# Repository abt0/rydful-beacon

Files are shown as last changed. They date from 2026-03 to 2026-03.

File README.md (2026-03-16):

# Rydful Beacon

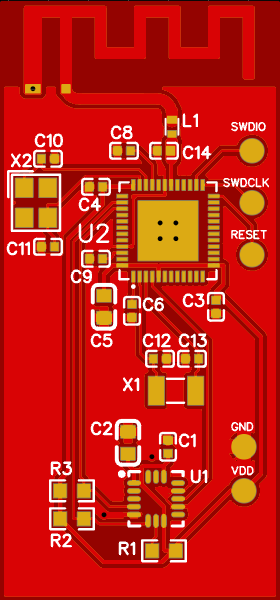
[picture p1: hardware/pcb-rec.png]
Rydful Beacon PCB


A motion-triggered BLE beacon application for Nordic nRF52 microcontrollers using the Zephyr RTOS. The device remains in sleep mode until motion is detected via an LIS3DH accelerometer, then starts BLE advertising to enable presence detection.

Designed for Rydful App: https://rydful.com

<br clear="left">

## Features

- **Hardware Interrupt-Driven Wake** – LIS3DH accelerometer's internal motion engine triggers MCU wake via GPIO interrupt (P0.02/INT1)
- **Ultra-Low Power Sleep** – MCU sleeps indefinitely with `k_sem_take(K_FOREVER)` until motion interrupt occurs (~3.9 µA total idle current)
- **Motion-Triggered Advertising** – BLE advertising starts only when motion exceeds hardware threshold (32mg default)
- **High-Pass Filtered Detection** – Gravity filtered out at 1Hz ODR in hardware, only acceleration changes trigger interrupt
- **Advertising Duty Cycling** – During active mode, advertising cycles 5s on / 7s off (~42% duty cycle) to reduce average power by ~45%
- **Configurable Timeouts** – Advertising stops after configurable period of no motion (default: 36 seconds, 3 full duty cycles)
- **Battery Voltage Monitoring** – ADC-based battery voltage measurement with percentage calculation, included in BLE advertising data (updated every 5 minutes)
- **Direct I2C Register Access** – Bypasses Zephyr sensor framework for reliable interrupt configuration
- **Android CDM Compatible** – 250-400ms connectable/scannable advertising interval for reliable companion app discovery

## Hardware Requirements

- **MCU**: Nordic nRF52832 (nRF52 DK)
- **Accelerometer**: LIS3DH or LIS2DH (I2C interface)
- **Battery**: 2.0-3.6V input (CR2032, 2× AAA/AA alkaline or lithium)

### Wiring (nRF52 DK with LIS3DH)

| LIS3DH Pin | nRF52 DK Pin | Description |
|---|---|---|
| SDA | P0.26 | I2C Data |
| SCL | P0.27 | I2C Clock |
| INT1 | P0.02 | Motion interrupt (required for low-power wake) |
| - | P0.03 (AIN1) | Battery voltage input |

## Supported Boards

| Board | Description | Use Case |
|---|---|---|
| `nrf52dk_nrf52832` | Nordic nRF52 DK | Development/testing with external LIS3DH |
| `rydful_custom` | Custom PCB | Production board with integrated LIS3DH |

## Configuration

### Hardware Motion Detection Parameters

These are defined in `src/main.c`:

| Parameter | Default | Description |
|---|---|---|
| `HW_MOTION_THRESHOLD_MG` | 32 mg | Acceleration threshold for motion detection |
| `HW_MOTION_DURATION` | 2 samples | Required samples above threshold (debounce) |
| `NO_MOTION_TIMEOUT_SEC` | 36 | Seconds of no motion before stopping advertising (3 full duty cycles) |
| `ADV_DUTY_ON_SEC` | 5 | Seconds of advertising per duty cycle |
| `ADV_DUTY_OFF_SEC` | 7 | Seconds of radio silence per duty cycle |

The LIS3DH operates at **1Hz ODR** in low-power mode (~2µA) and uses its internal high-pass filter to remove gravity, so only acceleration *changes* trigger the interrupt. Wake latency is ~1 second.

### Battery Monitoring

| Parameter | Default | Description |
|---|---|---|
| `BATTERY_LOW_THRESHOLD_MV` | 2000 mV | 0% battery threshold |
| `BATTERY_FULL_MV` | 3000 mV | 100% battery threshold |
| `BATTERY_UPDATE_INTERVAL_SEC` | 300 | Battery status update interval (5 minutes) |

### BLE Configuration

- **Device Name**: `Rydful_Beacon` (configurable via `CONFIG_BT_DEVICE_NAME`)
- **Service UUID**: `0xFEAA` (16-bit)
- **Manufacturer ID**: `0xFFFF` (development/testing)
- **Advertising Interval**: 250-400 ms (required for Android CDM compatibility)
- **Mode**: Connectable, scannable

### BLE Advertising Data

The manufacturer-specific data contains:
- Bytes 0-1: Manufacturer ID
- Byte 2: Battery percentage (0-100)
- Byte 3: Low battery flag (0x00 or 0x01)

## Building

### Prerequisites

- [nRF Connect SDK](https://docs.nordicsemi.com/bundle/ncs-latest/page/nrf/installation.html) installed
- West tool configured

### Build Commands

```bash
# Build for nRF52 DK (development/testing with external accelerometer)
west build -b nrf52dk/nrf52832 -p

# Build for Rydful Custom PCB (production board)
west build -b rydful_custom -p -- -DBOARD_ROOT=.
```

### Flash

```bash
# Flash nRF52 DK (direct connection)
west flash
```

## Flashing Custom PCB via nRF52 DK

The nRF52 DK can be used as a J-Link programmer to flash the custom PCB.

### Hardware Setup

1. **Disconnect** the nRF52 DK from USB
2. **Set the nRF power switch** to "VDD" (not "USB") on the DK
3. **Connect SWD wires** from DK P20 header to your custom PCB:

| DK P20 Pin | Custom PCB | Description |
|---|---|---|
| SWDIO | SWDIO | Debug data  |
| SWDCLK | SWDCLK | Debug clock |
| GND | GND | Ground |
| VTG | VDD | Target voltage sense (optional) |

4. **Power the custom PCB** via its own power source (external supply)
5. **Connect DK to USB** for programming

### Flash Command

```bash
# Build for custom PCB
west build -b rydful_custom -p -- -DBOARD_ROOT=.

# Flash via J-Link
west flash
```

### Troubleshooting

- **"No target detected"** – Check SWD wiring, ensure custom PCB is powered
- **"Could not connect"** – Verify SWDIO/SWDCLK connections, check for shorts
- **Use nRF Connect Programmer** – Alternative GUI tool for flashing `.hex` files from `build/zephyr/zephyr.hex`

### Using nrfjprog (Alternative)

```bash
# Erase and flash
nrfjprog --program build/zephyr/zephyr.hex --chiperase --verify
nrfjprog --reset
```

## How It Works

### State Machine

```
┌─────────────────────────────────────────────────────────────┐
│  SLEEP MODE                                                 │
│  • LIS3DH: Hardware threshold interrupt (>32mg) @ 1Hz       │
│  • nRF52: System ON sleep with LFXO (~1.8 µA)               │
│  • Total: ~3.9 µA                                           │
└──────────────────────┬──────────────────────────────────────┘
                       │ Motion exceeds threshold (~2s latency)
                       ▼
┌─────────────────────────────────────────────────────────────┐
│  ACTIVE MODE (duty-cycled: 5s ON / 7s OFF)                  │
│  • ON:  BLE advertising (connectable, 250-400ms, -12dBm TX) │
│  • OFF: Radio silent, MCU polling for motion (max 7s gap)   │
│  • Each motion interrupt resets 36-second timeout           │
│  • Duty cycle runs independently of motion events           │
│  • Average: ~30 µA                                          │
└──────────────────────┬──────────────────────────────────────┘
                       │ No motion for 36 seconds
                       ▼
              Back to SLEEP MODE
```

### Usage

1. **Power on** – Initialization sequence
2. **Sleep mode** – No BLE advertising, ultra-low power (~3.9 µA)
3. **Motion detected** – BLE advertising starts (~1 second wake latency)
4. **Active mode** – Advertising duty-cycles 5s on / 7s off; each motion event resets the 36-second timeout
5. **No motion** – After 36 seconds of no motion, advertising stops

### Monitoring

Connect via RTT console (production PCB) or serial (115200 baud) to view logs.

## Power Consumption

*Note: All estimates are for the production PCB (nRF52832 + LIS3DHTR + passives only).*

### Current Draw by State

| State | Current | Description |
|---|---|---|
| Sleep | ~3.9 µA | nRF52 System ON (~1.8µA with LFXO) + LIS3DH @ 1Hz (~2µA) |
| Active (duty-cycled) | ~30 µA avg | 5s advertising / 7s silent duty cycle (~42% radio on) |
| Active (ON phase) | ~55 µA | BLE connectable advertising @ 250-400ms, -12dBm TX |
| Active (OFF phase) | ~13 µA | Radio off, CPU polling for motion |
| Peak (TX burst) | ~7.5 mA | During BLE transmit events @ -12dBm (~380µs per event) |

### Component Breakdown (Sleep Mode)

| Component | Current | Notes |
|---|---|---|
| nRF52832 System ON (LFXO) | ~1.8 µA | RAM retained, RTC running, external 32.768kHz crystal |
| LIS3DHTR @ 1Hz LP mode | ~2 µA | Interrupt engine active, HP filter, 1s wake latency |
| GPIO leakage | ~0.1 µA | Minimal with proper configuration |
| **Total Sleep** | **~3.9 µA** | |

### Component Breakdown (Active Mode – ON Phase, 5s)

| Component | Current | Notes |
|---|---|---|
| BLE advertising | ~40 µA | 250-400ms interval, connectable/scannable, -12dBm TX |
| LIS3DHTR @ 1Hz | ~2 µA | Same ODR as sleep |
| ADC sampling (periodic) | ~1 µA avg | Brief spikes every 5 minutes |
| CPU overhead | ~10-12 µA | Processing interrupts, state management |
| **Total ON Phase** | **~55 µA** | 0.055 mA |

### Component Breakdown (Active Mode – OFF Phase, 7s)

| Component | Current | Notes |
|---|---|---|
| BLE advertising | 0 µA | Radio off |
| LIS3DHTR @ 1Hz | ~2 µA | Same ODR as sleep |
| ADC sampling (periodic) | ~1 µA avg | Brief spikes every 5 minutes |
| CPU overhead | ~10 µA | Polling loop (500ms wake intervals) |
| **Total OFF Phase** | **~13 µA** | 0.013 mA |

### Duty-Cycled Active Mode Average

```
I_active_avg = (I_on × T_on + I_off × T_off) / (T_on + T_off)
             = (55µA × 5s + 13µA × 7s) / (5s + 7s)
             = (275 + 91) / 12
             ≈ 30 µA (0.030 mA)
```

### Power Optimizations Applied

| Optimization | Impact | Trade-off |
|---|---|---|
| External 32.768kHz LFXO | ~70% MCU sleep reduction vs RC oscillator | None (hardware present) |
| Reduced TX power (-12dBm) | ~25% peak TX reduction, minimal avg impact | Tight 5m discovery range |
| LIS3DH 1Hz ODR | ~64% sensor sleep reduction | 1 second wake latency |
| **Advertising duty cycle (5s/7s)** | **~45% active mode reduction** (55→30 µA) | Up to 7s discovery gap |
| 36s no-motion timeout (3 duty cycles) | Minimizes active time | Aligned to duty cycle period |
| 5-minute battery updates | Negligible impact (<1 µA) | Less frequent battery status |

---

## Battery Life Calculations

*Production PCB with power optimizations: 1Hz accelerometer ODR, 5s/7s advertising duty cycle, 36s timeout, 5-min battery updates.*

### Supported Power Sources

| Battery Type | Nominal Voltage | Typical Capacity | Effective Capacity* |
|---|---|---|---|
| CR2032 | 3.0V | 225 mAh | ~150 mAh** |
| 2× AAA Alkaline | 3.0V (1.5V × 2) | 1,200 mAh | ~1,000 mAh |
| 2× AA Alkaline | 3.0V (1.5V × 2) | 2,850 mAh | ~2,400 mAh |
| 2× AA Lithium | 3.0V (1.5V × 2) | 3,500 mAh | ~3,000 mAh |

*Effective capacity accounts for ~15-20% derating due to voltage cutoff (2.0V minimum), temperature, and discharge curve.

**CR2032 Pulse Current Derating:** CR2032 batteries experience significant capacity reduction under pulse loads. While average current is low (~55 µA active), the 7.5 mA TX peaks (though brief, ~380µs every 325ms) cause additional derating. Effective capacity reduced from nominal 225 mAh to ~150 mAh for this application. For comparison: at 0.5 mA continuous draw CR2032 provides ~240 mAh, but at 3.0 mA only ~155 mAh remains available.

### Usage Pattern Definitions

| Pattern | Description | Daily Active Time | Trips/Day |
|---|---|---|---|
| **Parked Vehicle** | Garaged/parked, minimal vibration | ~5-15 min | 0-1 |
| **Weekend Rider** | Motorcycle/classic car, weekend use only | ~2-4 hours | 1-2 (weekends only) |
| **Commuter** | Daily work commute, 2× per day ~1h each | ~2 hours | 2 |
| **Daily Driver** | Multiple short trips throughout day | ~3 hours | 4-6 |
| **Heavy Use** | Delivery/rideshare, constant use | ~8-12 hours | 10-20 |

### Battery Life Formula

```
Total Daily Consumption (mAh/day) = (I_sleep × T_sleep) + (I_active × T_active)

Where:
  I_sleep  = 0.0039 mA (3.9 µA with external LFXO)
  I_active = 0.030 mA (duty-cycled average: 5s ON @ 55µA, 7s OFF @ 13µA)
  T_sleep  = 24 - T_active (hours)
  T_active = Active hours per day + (trips × timeout / 3600)
  timeout  = 36 seconds (advertising continues after last motion, 3 duty cycles)

Battery Life (days) = Effective_Capacity / Daily_Consumption
```

### Detailed Lifetime Estimates

#### CR2032 (150 mAh effective, pulse-derated)

| Usage Pattern | Active Hours/Day | Daily Draw (mAh) | Estimated Life |
|---|---|---|---|
| Parked Vehicle | 0.26h | 0.10 | **1,500 days** (~4.1 years)† |
| Weekend Rider | 0.59h (avg)* | 0.11 | **1,376 days** (~3.8 years)† |
| Commuter (2×/day) | 2.02h | 0.15 | **1,027 days** (~2.8 years) |
| Daily Driver | 3.05h | 0.17 | **867 days** (~2.4 years) |
| Heavy Use | 8.15h | 0.31 | **490 days** (~1.3 years) |

*Weekend rider averaged over 7 days
†CR2032 self-discharge ~10-15% per year; practical life 2-3 years for commuter/daily use due to pulse derating and environmental factors

#### 2× AAA Alkaline (1,000 mAh effective)

| Usage Pattern | Active Hours/Day | Daily Draw (mAh) | Estimated Life |
|---|---|---|---|
| Parked Vehicle | 0.26h | 0.10 | **10,000 days** (~27.4 years)† |
| Weekend Rider | 0.59h (avg) | 0.11 | **9,174 days** (~25.1 years)† |
| Commuter (2×/day) | 2.02h | 0.15 | **6,849 days** (~18.8 years)† |
| Daily Driver | 3.05h | 0.17 | **5,780 days** (~15.8 years)† |
| Heavy Use | 8.15h | 0.31 | **3,268 days** (~8.9 years)† |

†Limited by battery self-discharge (~2-3% per year), practical limit ~5-7 years.

#### 2× AA Alkaline (2,400 mAh effective)

| Usage Pattern | Active Hours/Day | Daily Draw (mAh) | Estimated Life |
|---|---|---|---|
| Parked Vehicle | 0.26h | 0.10 | **24,000 days** (~66 years)† |
| Weekend Rider | 0.59h (avg) | 0.11 | **22,018 days** (~60 years)† |
| Commuter (2×/day) | 2.02h | 0.15 | **16,438 days** (~45 years)† |
| Daily Driver | 3.05h | 0.17 | **13,873 days** (~38 years)† |
| Heavy Use | 8.15h | 0.31 | **7,843 days** (~21 years)† |

†Alkaline batteries self-discharge ~2-3% per year. Actual life limited to ~5-7 years maximum regardless of load.

#### 2× AA Lithium (3,000 mAh effective)

| Usage Pattern | Active Hours/Day | Daily Draw (mAh) | Estimated Life |
|---|---|---|---|
| Parked Vehicle | 0.26h | 0.10 | **30,000 days** (~82 years)† |
| Weekend Rider | 0.59h (avg) | 0.11 | **27,523 days** (~75 years)† |
| Commuter (2×/day) | 2.02h | 0.15 | **20,548 days** (~56 years)† |
| Daily Driver | 3.05h | 0.17 | **17,341 days** (~47 years)† |
| Heavy Use | 8.15h | 0.31 | **9,804 days** (~27 years)† |

†Lithium batteries have ~1% annual self-discharge. Practical limit ~10 years.

### Commuter Scenario Deep Dive (2× daily, ~1h each)

This is a common use case: daily work commute with two trips.

**Calculation breakdown:**
- Morning commute: 1 hour active
- Evening commute: 1 hour active
- Post-trip timeout: 36 seconds × 2 trips = 1.2 minutes
- **Total active time**: 2h 1.2min/day ≈ 2.02 hours

**Daily energy consumption:**
```
Sleep:   (24 - 2.02)h × 0.0039mA = 0.086 mAh
Active:  2.02h × 0.030mA         = 0.061 mAh
─────────────────────────────────────────────
Total:                           = 0.146 mAh/day
```

| Battery Type | Capacity | Estimated Life | Practical Reality |
|---|---|---|---|
| CR2032 | 150 mAh | **1,027 days** (~2.8 years) | 2-3 years typical |
| 2× AAA | 1,000 mAh | **6,849 days** (~18.8 years)† | 5-7 years (self-discharge limit) |
| 2× AA | 2,400 mAh | **16,438 days** (~45 years)† | 5-7 years (self-discharge limit) |
| 2× AA Lithium | 3,000 mAh | **20,548 days** (~56 years)† | 10+ years (self-discharge limit) |

†Limited by battery self-discharge, not device consumption

### Temperature Impact

Battery performance degrades significantly in extreme temperatures:

| Temperature | Capacity Factor | Notes |
|---|---|---|
| -20°C to -10°C | 50-70% | Severe cold reduces capacity |
| -10°C to 0°C | 70-85% | Cold weather impact |
| 0°C to 25°C | 85-100% | Optimal operating range |
| 25°C to 45°C | 90-100% | Warm, generally fine |
| >45°C | Reduced lifespan | Accelerated self-discharge |

**Recommendation**: For vehicles parked outdoors in extreme climates, use **lithium primary cells** (2× AA Lithium) which maintain 90%+ capacity down to -40°C.

### Battery Selection Guide

| Use Case | Recommended | Rationale |
|---|---|---|
| **Motorcycle (Weekend)** | 2× AAA | AAA: 5-7 years (self-discharge limited), better than CR2032 for longevity |
| **Daily Commuter** | 2× AAA | **5-7 years** (self-discharge limited), compact form factor |
| **Daily Commuter (extended)** | 2× AA | **5-7 years** (self-discharge limited), best longevity |
| **Delivery Vehicle** | 2× AA or 2× AA Lithium | AA: ~5 years, Lithium: 10+ years |
| **Garage Queen** | 2× AAA | Multi-year life, minimal replacement (AAA better than CR2032) |
| **Extreme Cold Climate** | 2× AA Lithium | Maintains capacity at low temps, 10+ years |
| **Compact Installation** | CR2032 | Small size, **2-3 years typical** (pulse current limits lifespan) |

### Quick Reference: Months Until Replacement

|  | CR2032** | 2× AAA | 2× AA | 2× AA Li |
|--|---|---|---|---|
| **Parked** | 49 mo | 60+ mo* | 60+ mo* | 120+ mo* |
| **Weekend** | 45 mo | 60+ mo* | 60+ mo* | 120+ mo* |
| **Commuter** | **34 mo** | 60+ mo* | 60+ mo* | 120+ mo* |
| **Daily** | 28 mo | 60+ mo* | 60+ mo* | 120+ mo* |
| **Heavy** | 16 mo | 60+ mo* | 60+ mo* | 120+ mo* |

*Limited by battery self-discharge (~5-7 years for alkaline, ~10 years for lithium), not device consumption
**CR2032 estimates account for pulse current derating; real-world life often 2-3 years for commuter/daily use due to environmental factors

---

## Case Designs

The project includes 3D-printable case designs for different battery configurations:

### Available Cases

| Case Type | Battery | Design File | STL Files | Dimensions | Features |
|---|---|---|---|---|---|
| **Circular** | CR2032 | `circular.scad` | `circular_base.stl`, `circular_lid.stl` | Ø35mm × 12.5mm | Compact circular design, snap-fit lid, mounting tabs |
| **Rectangular** | 2×AA | `rectangular.scad` | `rectangular_base.stl`, `rectangular_lid.stl` | 89mm × 40mm × 15mm | Side-by-side AA batteries, spring contacts, PCB rails |

### Case Features

**Circular Case**
- Designed for CR2032 coin cell battery
- 30mm diameter circular PCB mounting
- 3 tapered support nubs at 90°/210°/330° angles
- Snap-fit lid with 0.05mm interference fit for MJF printing
- Mounting tabs with 3.2mm screw holes
- "Rydful" engraved text on lid
- Fingernail pry notches for easy lid removal

**Rectangular Case**
- Designed for 2×AA batteries in side-by-side configuration
- Spring contact pockets for reliable battery connections
- PCB slide-in rails with L-shaped channels
- 4 corner standoffs for PCB support
- Divider wall between battery and PCB sections
- Snap-fit lid with multiple engagement points
- Battery cradle with cylindrical channels
- "Rydful" engraved text on lid

### 3D Printing

- **Recommended material**: MJF (Multi Jet Fusion) or FDM with PETG/ABS
- **Layer height**: 0.2mm for FDM
- **Infill**: 20-30% (cases are primarily hollow)
- **Orientation**: Print with flat side down for best surface finish
- **Post-processing**: Remove support material, check snap-fit engagement

### Assembly

1. Install batteries in designated compartments
2. Route PCB into case (slide-in rails for rectangular case)
3. Ensure proper alignment of snap-fit features
4. Press lid firmly until snap engagement is felt
5. Test lid removal using pry notches if needed

SPDX-License-Identifier: Apache-2.0

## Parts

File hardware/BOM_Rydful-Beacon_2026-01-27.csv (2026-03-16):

ID | Name | Designator | Footprint | Quantity | Supplier | Supplier Part | Price
1 | 100nF | C1,C3,C4,C6 | C0402 | 4 | LCSC | C60474 | 0.001
2 | 10uF | C2 | C0603 | 1 | LCSC | C19702 | 0.007
3 | 4.7uF | C5 | C0603 | 1 | LCSC | C18185770 | 0.011
4 | 100pF | C8 | C0402 | 1 | LCSC | C526991 | 0.001
5 | 1uF | C9 | C0402 | 1 | LCSC | C29266 | 0.003
6 | 6pF | C10,C11 | C0402 | 2 | LCSC | C696878 | 0.001
7 | 15pF | C12,C13 | C0402 | 2 | LCSC | C1548 | 0.001
8 | 0.8pF | C14 | C0402 | 1 | LCSC | C40459 | 0.002
9 | 3.9nH | L1 | IND-SMD_L1.0-W0.5-2 | 1 | LCSC | C98062 | 0.032
10 | 10kΩ | R1 | R0402 | 1 | LCSC | C25744 | 0.001
11 | 4.7kΩ | R2,R3 | R0402 | 2 | LCSC | C25900 | 0.001
12 | LIS3DH | U1 | LGA-16_L3.0-W3.0-P0.50-TL | 1 | LCSC | C15134 | 0.765
13 | NRF52832 V2 | U2 | QFN-48_L6.0-W6.0-P0.40-BL-EP3.8 | 1 | LCSC | C77540 | 2.807
14 | 32.768kHz | X1 | CRYSTAL-SMD_L3.2-W1.5-FC-135R32.7680KF-A3 | 1 | LCSC | C37635362 | 0.18
15 | 32MHz | X2 | CRYSTAL-SMD_4P-L2.5-W2.0-BL | 1 | LCSC | C524677 | 0.17

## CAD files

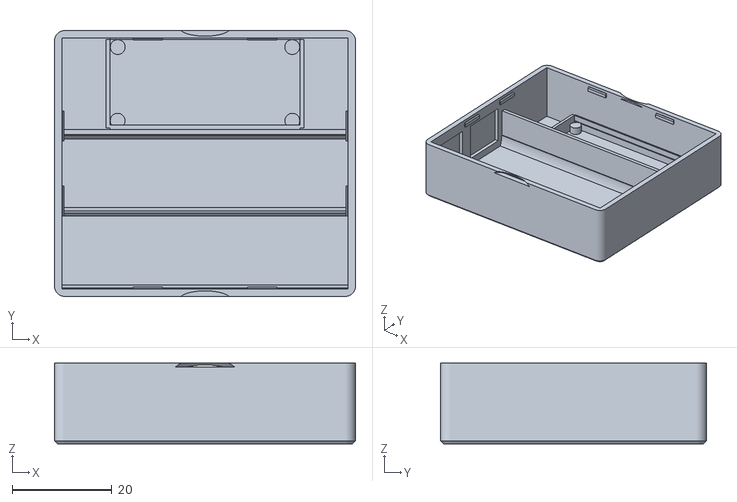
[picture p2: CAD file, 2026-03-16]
case/rectangular_base.stl
60.5 x 53.4 x 16.2

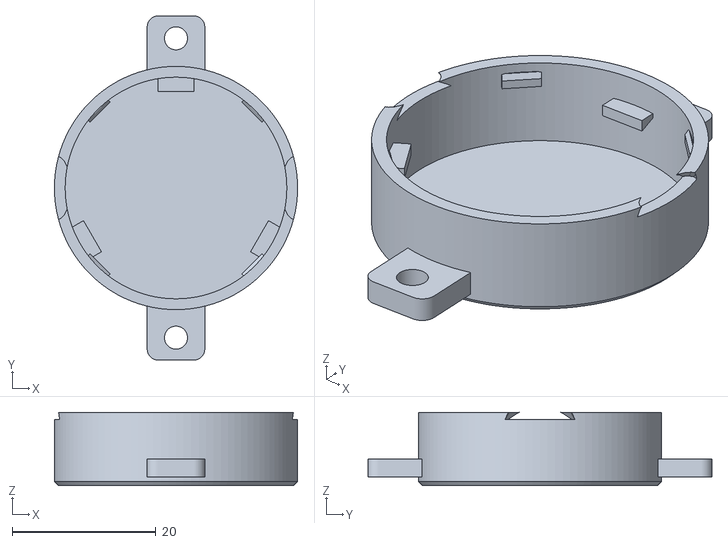
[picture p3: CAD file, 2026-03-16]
case/circlular_base.stl
33.8 x 47.8 x 10.2

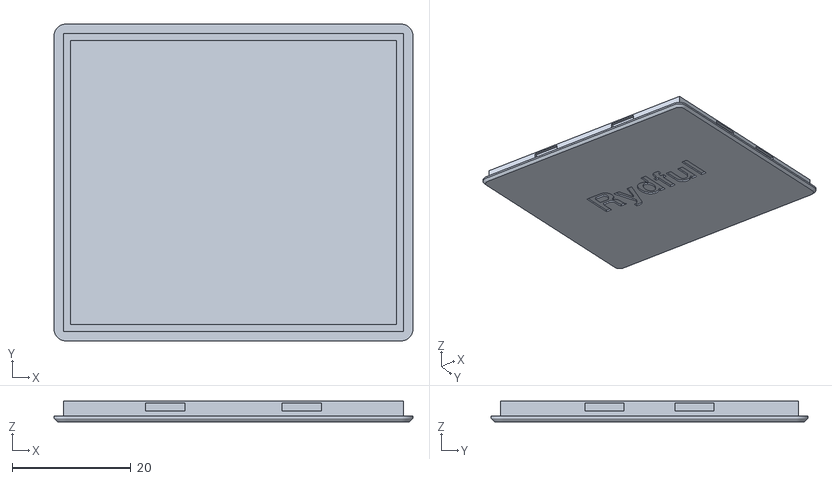
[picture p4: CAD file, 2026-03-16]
case/rectangular_lid.stl
60.5 x 53.4 x 3.50

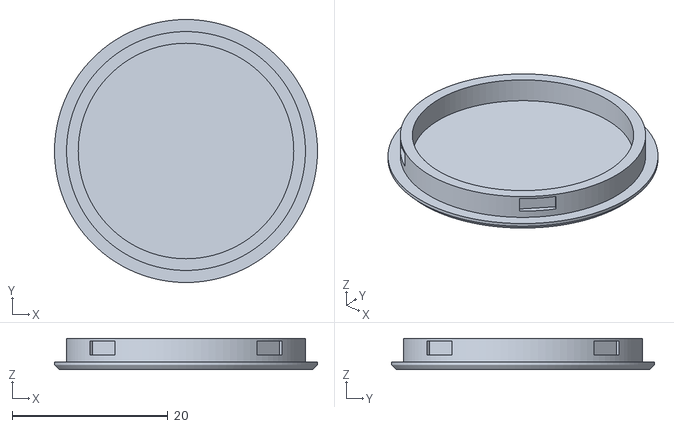
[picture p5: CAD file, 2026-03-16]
case/circular_lid.stl
33.8 x 33.8 x 4.00

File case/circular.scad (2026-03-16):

// ==============================================
// Rydful-Beacon Case v6 — JLC3DP MJF
// - No ring ledge (holder too close to PCB edge)
// - 3 tapered nubs at 90°/210°/330° for PCB support
// - 0.5mm snap bumps + 0.05mm interference skirt fit
// - Fingernail pry notches at ±X (away from tabs)
// - Orient PCB: holder long axis along ±X
// ==============================================

pcb_dia       = 30;
pcb_thk       = 1.0;
comp_h        = 2.0;     // Max component height above PCB
batt_h        = 6.0;     // BS-8-1 + CR2032 below PCB (0.8mm margin)

wall          = 1.5;
gap           = 0.4;     // Radial PCB clearance
floor_h       = 1.2;
ceil_h        = 1.0;
chamfer       = 0.6;

// Snap-fit — firmer engagement
snap_bump     = 0.5;     // Bump protrusion
snap_h        = 1.5;     // Bump height
snap_chamf    = 0.6;     // Entry chamfer

skirt_d       = 3.0;     // Lid skirt depth (was 2.5)
lid_gap       = 0.05;    // Near-zero for interference fit (MJF ±0.2mm)

tab_w         = 8.0;
tab_ext       = 7.0;
tab_h         = 2.5;
screw_d       = 3.2;
tab_r         = 1.5;

engrave_depth = 0.4;   // Text engraving depth (mm)
engrave_w     = 16;    // Text width (mm)

$fn = 100;

// Derived
ir = pcb_dia/2 + gap;
or = ir + wall;
cav_h = batt_h + pcb_thk + comp_h;
base_h = floor_h + cav_h;
pcb_z = floor_h + batt_h;

echo(str("Outer Ø=", or*2, "  Base H=", base_h, "  Total=", base_h + ceil_h));
echo(str("PCB Z=", pcb_z, "  Inner Ø=", ir*2));

// ==============================================
// CHAMFERED CYLINDER
// ==============================================
module cham_cyl_bot(r, h, c) {
    hull() {
        translate([0, 0, c])
            cylinder(h = h - c, r = r);
        cylinder(h = 0.01, r = r - c);
    }
}

module cham_cyl_top(r, h, c) {
    hull() {
        cylinder(h = h - c, r = r);
        translate([0, 0, h - 0.01])
            cylinder(h = 0.01, r = r - c);
    }
}

// ==============================================
// MOUNT TAB
// ==============================================
module mount_tab() {
    overlap = 3;
    total_l = tab_ext + overlap;
    difference() {
        hull() {
            translate([-tab_w/2, -overlap, 0])
                cube([tab_w, 0.01, tab_h]);
            translate([-tab_w/2 + tab_r, total_l - overlap - tab_r, 0])
                cylinder(h = tab_h, r = tab_r);
            translate([tab_w/2 - tab_r, total_l - overlap - tab_r, 0])
                cylinder(h = tab_h, r = tab_r);
        }
        translate([0, tab_ext - tab_r - screw_d/2, -0.1])
            cylinder(h = tab_h + 0.2, d = screw_d);
    }
}

// ==============================================
// PCB SUPPORT NUBS
// ==============================================
// Tapered nubs on interior wall at pcb_z height
// Positioned in equilateral triangle at 90°/210°/330°
// All 30°+ away from ±X where holder pads reach PCB edge
module pcb_support_nubs() {
    nub_w = 5;       // Width along wall (mm)
    nub_depth = 2.0; // How far nub sticks inward (inner edge at 13.4mm from center)
    nub_h = 1.2;     // Height (supports PCB from below)

    // Nub positions: 90° (+Y, top), 210°, 330° — equilateral triangle
    // ALL positions are 30°+ away from ±X (holder long axis)
    // Holder short axis only reaches 7.85mm from center, so
    // at these angles the holder edge is well inside the nub zone.
    for (a = [90, 210, 330]) {
        rotate([0, 0, a])
        translate([ir - nub_depth, -nub_w/2, pcb_z - nub_h])
        hull() {
            // Full shelf at wall
            cube([0.1, nub_w, nub_h]);
            // Tapered inner edge for easy PCB drop-in
            translate([nub_depth, 0, nub_h - 0.4])
                cube([0.1, nub_w, 0.4]);
        }
    }
}

// ==============================================
// BASE
// ==============================================
module base() {
    difference() {
        union() {
            // Main shell
            cham_cyl_bot(or, base_h, chamfer);

            // Tabs
            translate([0, or, floor_h])
                mount_tab();
            rotate([0, 0, 180])
            translate([0, or, floor_h])
                mount_tab();

            // Snap bumps — 4x on inner wall near top
            // (added after hollow cut below)
        }

        // Hollow interior
        translate([0, 0, floor_h])
            cylinder(h = cav_h + 1, r = ir);

        // Fingernail pry notches — scoop at lid/base seam
        // At 0° and 180° (±X) — away from tabs (±Y) and nubs
        for (a = [0, 180]) {
            rotate([0, 0, a])
            translate([or - 1.2, 0, base_h - 1.0])
            scale([1, 2.5, 1])
            hull() {
                translate([0, 0, 0]) cylinder(d = 4, h = 0.01, $fn = 24);
                translate([1.5, 0, 2.0]) cylinder(d = 3, h = 0.01, $fn = 24);
            }
        }
    }

    // PCB support nubs (added after hollow)
    pcb_support_nubs();

    // Snap bumps — protrude inward from wall into cavity
    // Lid skirt slides past these; grooves in skirt catch them
    for (i = [0:3]) {
        a = i * 90 + 45;
        rotate([0, 0, a])
        translate([ir - snap_bump, -2, base_h - skirt_d + 0.5])
        hull() {
            // Full bump at wall
            translate([snap_bump - 0.1, 0, 0])
                cube([0.1, 4, snap_h - snap_chamf]);
            // Tapered tip toward center (entry chamfer)
            cube([0.1, 4, snap_h - snap_chamf]);
            // Chamfer top for smooth lid insertion
            translate([snap_bump - 0.1, 0, snap_h - snap_chamf])
                cube([0.1, 4, snap_chamf]);
        }
    }
}

// ==============================================
// LID
// ==============================================
module lid() {
    skirt_or = ir - lid_gap;         // Skirt outer = fits inside base wall
    skirt_ir = skirt_or - wall;      // Skirt inner

    difference() {
        union() {
            // Ceiling
            cham_cyl_top(or, ceil_h, chamfer);

            // Skirt (internal, nests inside base)
            translate([0, 0, -skirt_d])
            difference() {
                cylinder(h = skirt_d, r = skirt_or);
                translate([0, 0, -0.01])
                    cylinder(h = skirt_d + 0.02, r = skirt_ir);
            }
        }

        // Snap grooves — channels in skirt outer surface
        // When lid is inserted, bumps deflect the skirt inward,
        // then pop into these grooves for a click-lock
        for (i = [0:3]) {
            a = i * 90 + 45;
            rotate([0, 0, a])
            translate([skirt_or - snap_bump - 0.2, -2.3, -skirt_d + 0.3])
                cube([snap_bump + 0.4, 4.6, snap_h + 0.3]);
        }

        // Engraved "Rydful" text centered on lid top
        translate([0, 0, ceil_h - engrave_depth])
            linear_extrude(engrave_depth + 0.01)
                resize([engrave_w, 0], auto=true)
                    text("Rydful", halign="center", valign="center",
                         font="Liberation Sans:style=Bold");
    }
}

// ==============================================
// RENDER — comment out for export
// ==============================================
// base();
// rotate([180,0,0]) lid();

color("DimGray") base();
color("SlateBlue", 0.7) translate([0, 0, base_h]) lid();
%translate([0, 0, pcb_z]) cylinder(h = pcb_thk, r = pcb_dia/2);
%translate([0, 0, floor_h + 0.5]) cylinder(h = 3.2, d = 20);

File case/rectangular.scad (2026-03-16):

// =============================================
// Rydful-Beacon Rectangular Case v1 — 2×AA
// - 2×AA side by side with spring contacts
// - PCB 17.8×38.1mm beside batteries
// - Snap-fit lid, rounded corners
// - Orient: batteries along X, PCB beside in Y
// =============================================

// AA Battery
aa_dia        = 14.5;   // Battery diameter
aa_len        = 50.5;   // Battery length (incl. positive nub)
spring_cl     = 3.5;    // Spring contact clearance per end
batt_gap      = 1.0;    // Gap between two batteries
batt_cl       = 0.5;    // Battery clearance to walls
cradle_depth  = 3.0;    // Cradle channel depth

// PCB
pcb_l         = 38.1;   // Length (X)
pcb_w         = 17.8;   // Width (Y)
pcb_thk       = 1.6;
comp_h        = 2.0;    // Max component height (top side)
pcb_gap       = 0.3;    // Clearance around PCB

// Case
wall          = 1.5;
floor_h       = 1.2;
ceil_h        = 1.0;
corner_r      = 2.0;
chamfer       = 0.6;
div_wall      = 1.0;    // Divider between battery/PCB sections

// Snap-fit
snap_bump     = 0.4;
snap_h        = 1.2;
snap_chamf    = 0.3;

// Lid
skirt_d       = 2.5;
lid_gap       = 0.1;
sk_wall       = 1.2;    // Skirt wall thickness

// PCB support
standoff_h    = 2.0;
standoff_d    = 3.0;

// Text engraving
engrave_depth = 0.4;
engrave_w     = 30;     // Text width (mm)

// Spring contact pockets
contact_w     = 12.0;   // Contact plate width
contact_h     = 10.0;   // Contact plate height
contact_d     = 1.0;    // Pocket depth into wall

$fn = 60;

// ---- Derived ----
batt_sec_x = aa_len + 2 * spring_cl;
batt_sec_y = 2 * aa_dia + batt_gap + 2 * batt_cl;
pcb_sec_y  = pcb_w + 2 * pcb_gap;

cav_x = batt_sec_x;
cav_y = batt_sec_y + div_wall + pcb_sec_y;
cav_z = aa_dia + batt_cl;

ext_x = cav_x + 2 * wall;
ext_y = cav_y + 2 * wall;
base_h = floor_h + cav_z;

// PCB origin inside cavity
pcb_ox = wall + (cav_x - pcb_l) / 2;
pcb_oy = wall + batt_sec_y + div_wall + pcb_gap;

echo(str("Case: ", ext_x, " × ", ext_y, " × ", base_h + ceil_h, " mm"));
echo(str("Battery section: ", batt_sec_x, " × ", batt_sec_y, " mm"));
echo(str("PCB section: ", cav_x, " × ", pcb_sec_y, " mm"));

// =============================================
// ROUNDED RECTANGLE (2D)
// =============================================
module rrect(x, y, r) {
    offset(r) offset(-r)
        square([x, y]);
}

// =============================================
// CHAMFERED ROUNDED RECTANGLE
// =============================================
module cham_rrect_bot(x, y, h, r, c) {
    hull() {
        linear_extrude(0.01)
            translate([c, c])
                rrect(x - 2*c, y - 2*c, max(r - c, 0.1));
        translate([0, 0, c])
            linear_extrude(h - c)
                rrect(x, y, r);
    }
}

module cham_rrect_top(x, y, h, r, c) {
    hull() {
        linear_extrude(h - c)
            rrect(x, y, r);
        translate([c, c, h - 0.01])
            linear_extrude(0.01)
                rrect(x - 2*c, y - 2*c, max(r - c, 0.1));
    }
}

// =============================================
// BASE
// =============================================
module base() {
    difference() {
        // Outer shell (chamfered bottom edge)
        cham_rrect_bot(ext_x, ext_y, base_h, corner_r, chamfer);

        // Internal cavity
        translate([wall, wall, floor_h])
            cube([cav_x, cav_y, cav_z + 1]);

        // Spring contact pockets — recesses in end walls (glue contacts in)
        for (i = [0, 1]) {
            batt_cy = wall + batt_cl + aa_dia/2 + i * (aa_dia + batt_gap);
            pocket_z = floor_h + cradle_depth - 1;

            // Negative end (X=0 wall)
            translate([wall - contact_d, batt_cy - contact_w/2, pocket_z])
                cube([contact_d + 0.1, contact_w, contact_h]);
            // Positive end (X=max wall)
            translate([wall + cav_x - 0.1, batt_cy - contact_w/2, pocket_z])
                cube([contact_d + 0.1, contact_w, contact_h]);
        }

        // Fingernail pry notches — centered on long sides
        for (dy = [0, ext_y]) {
            translate([ext_x/2, dy, base_h - 0.8])
            scale([3, 1, 1])
            hull() {
                cylinder(d = 4, h = 0.01, $fn = 24);
                translate([0, dy == 0 ? -1.2 : 1.2, 1.5])
                    cylinder(d = 3, h = 0.01, $fn = 24);
            }
        }
    }

    // ---- Internal features (added after hollow) ----

    // Battery cradle — raised floor with cylindrical channels
    difference() {
        translate([wall, wall, floor_h])
            cube([batt_sec_x, batt_sec_y, cradle_depth]);

        for (i = [0, 1]) {
            by = wall + batt_cl + aa_dia/2 + i * (aa_dia + batt_gap);
            translate([wall - 0.1, by, floor_h + cradle_depth])
                rotate([0, 90, 0])
                    cylinder(d = aa_dia + 0.6, h = batt_sec_x + 0.2);
        }
    }

    // Divider wall (70% height — open top for wire routing)
    translate([wall, wall + batt_sec_y, floor_h])
        cube([cav_x, div_wall, cav_z * 0.7]);

    // PCB standoffs — 4 posts near PCB corners
    for (dx = [1.5, pcb_l - 1.5], dy = [1.5, pcb_w - 1.5])
        translate([pcb_ox + dx, pcb_oy + dy, floor_h])
            cylinder(d = standoff_d, h = standoff_h, $fn = 20);

    // PCB slide-in rails (Y sides) — L-shaped channels that capture PCB edges
    rail_lip   = 0.6;    // Lip overhang over PCB edge
    rail_wall  = 0.8;    // Rail outer wall thickness
    rail_h     = standoff_h + pcb_thk + 0.3;  // Full height incl. lip
    rail_slot  = pcb_thk + 0.2;  // Slot height (PCB + clearance)

    for (side = [0, 1]) {
        ry = side == 0
            ? pcb_oy - rail_wall          // Near side
            : pcb_oy + pcb_w;             // Far side
        translate([pcb_ox, ry, floor_h]) {
            // Base wall (full height below PCB lip)
            cube([pcb_l, rail_wall, standoff_h]);
            // Upper wall (below PCB)
            cube([pcb_l, rail_wall + rail_lip, standoff_h]);
            // Lip overhang (above PCB slot)
            translate([0, 0, standoff_h + rail_slot])
                cube([pcb_l, rail_wall + rail_lip, rail_h - standoff_h - rail_slot]);
        }
    }

    // PCB end stops (X sides) — short walls at both ends
    stop_h = standoff_h + pcb_thk + 0.3;
    stop_w = 0.8;
    // Near X end
    translate([pcb_ox - stop_w, pcb_oy, floor_h])
        cube([stop_w, pcb_w, stop_h]);
    // Far X end
    translate([pcb_ox + pcb_l, pcb_oy, floor_h])
        cube([stop_w, pcb_w, stop_h]);

    // Snap bumps — protrude from inner walls into cavity
    bump_z = base_h - skirt_d + 0.5;
    bump_w = 6;

    // On Y walls (long sides)
    for (sx = [wall + cav_x * 0.3, wall + cav_x * 0.7]) {
        // Near Y wall
        translate([sx - bump_w/2, wall, bump_z])
        hull() {
            cube([bump_w, snap_bump, snap_h - snap_chamf]);
            translate([0, 0, snap_h - snap_chamf])
                cube([bump_w, 0.1, snap_chamf]);
        }
        // Far Y wall
        translate([sx - bump_w/2, wall + cav_y - snap_bump, bump_z])
        hull() {
            cube([bump_w, snap_bump, snap_h - snap_chamf]);
            translate([0, snap_bump - 0.1, snap_h - snap_chamf])
                cube([bump_w, 0.1, snap_chamf]);
        }
    }

    // On X walls (short sides)
    for (sy = [wall + cav_y * 0.35, wall + cav_y * 0.65]) {
        // Near X wall
        translate([wall, sy - bump_w/2, bump_z])
        hull() {
            cube([snap_bump, bump_w, snap_h - snap_chamf]);
            translate([0, 0, snap_h - snap_chamf])
                cube([0.1, bump_w, snap_chamf]);
        }
        // Far X wall
        translate([wall + cav_x - snap_bump, sy - bump_w/2, bump_z])
        hull() {
            cube([snap_bump, bump_w, snap_h - snap_chamf]);
            translate([snap_bump - 0.1, 0, snap_h - snap_chamf])
                cube([0.1, bump_w, snap_chamf]);
        }
    }
}

// =============================================
// LID
// =============================================
module lid() {
    skirt_x = cav_x - 2 * lid_gap;
    skirt_y = cav_y - 2 * lid_gap;
    bump_w  = 6;

    difference() {
        union() {
            // Top plate (chamfered top edge)
            cham_rrect_top(ext_x, ext_y, ceil_h, corner_r, chamfer);

            // Skirt (nests inside base cavity)
            translate([wall + lid_gap, wall + lid_gap, -skirt_d])
            difference() {
                cube([skirt_x, skirt_y, skirt_d]);
                translate([sk_wall, sk_wall, -0.01])
                    cube([skirt_x - 2*sk_wall, skirt_y - 2*sk_wall,
                          skirt_d + 0.02]);
            }
        }
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

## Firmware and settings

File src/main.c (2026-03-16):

/*
 * BLE Beacon - Hardware Interrupt-Driven Motion Detection
 *
 * Uses LIS3DH accelerometer's internal motion detection engine to wake the MCU
 * only when actual motion occurs, achieving ultra-low power consumption (~2.5 µA sleep).
 *
 * The LIS3DH operates at 1Hz in low-power mode with high-pass filtering to remove
 * gravity, triggering an interrupt only on acceleration *changes* above threshold.
 */

#include <zephyr/kernel.h>
#include <zephyr/bluetooth/bluetooth.h>
#include <zephyr/device.h>
#include <zephyr/drivers/gpio.h>
#include <zephyr/drivers/i2c.h>
#include <zephyr/drivers/adc.h>
#include <zephyr/logging/log.h>
#include <hal/nrf_saadc.h>

LOG_MODULE_REGISTER(beacon, LOG_LEVEL_INF);

/*
 * Configuration Parameters
 */

/* Motion detection threshold in mg */
#define HW_MOTION_THRESHOLD_MG    32

/* Number of samples above threshold before triggering */
#define HW_MOTION_DURATION        2

/* Seconds of no motion before stopping advertising (3 full duty cycles) */
#define NO_MOTION_TIMEOUT_SEC     36

/* Advertising duty cycle: advertise for 5s, pause for 7s */
#define ADV_DUTY_ON_SEC           5
#define ADV_DUTY_OFF_SEC          7

/* Battery monitoring configuration */
#define BATTERY_LOW_THRESHOLD_MV  2000  /* 0% battery level */
#define BATTERY_FULL_MV           3000  /* 100% battery level */
#define BATTERY_UPDATE_INTERVAL_SEC 300 /* Update every 5 minutes */

/* ADC configuration for battery voltage measurement */
#define ADC_NODE                  DT_NODELABEL(adc)
#define ADC_CHANNEL_ID            0
#define ADC_RESOLUTION_BITS       12
#define ADC_GAIN                  ADC_GAIN_1_6
#define ADC_REFERENCE             ADC_REF_INTERNAL
#define ADC_REF_MV                600  /* Internal reference is 0.6V */
#define ADC_RESOLUTION            ((1 << ADC_RESOLUTION_BITS) - 1)  /* 4095 for 12-bit */

/*
 * LIS2DH/LIS3DH Register Definitions
 * (Using direct I2C access for reliable interrupt configuration)
 */

/* Control registers */
#define LIS2DH_REG_CTRL_REG1      0x20
#define LIS2DH_REG_CTRL_REG2      0x21
#define LIS2DH_REG_CTRL_REG3      0x22
#define LIS2DH_REG_CTRL_REG4      0x23
#define LIS2DH_REG_CTRL_REG5      0x24
#define LIS2DH_REG_CTRL_REG6      0x25
#define LIS2DH_REG_REFERENCE      0x26

/* Interrupt configuration registers */
#define LIS2DH_REG_INT1_CFG       0x30
#define LIS2DH_REG_INT1_SRC       0x31
#define LIS2DH_REG_INT1_THS       0x32
#define LIS2DH_REG_INT1_DURATION  0x33

/* Identification */
#define LIS2DH_REG_WHO_AM_I       0x0F
#define LIS2DH_WHO_AM_I_VALUE     0x33

/* CTRL_REG1 bits */
#define LIS2DH_ODR_1HZ            (0x01 << 4)  /* 1Hz output data rate */
#define LIS2DH_LPEN               BIT(3)       /* Low-power mode enable */
#define LIS2DH_XYZ_EN             0x07         /* Enable X, Y, Z axes */

/* CTRL_REG2 bits */
#define LIS2DH_HP_IA1             BIT(0)       /* HP filter for interrupt 1 */
#define LIS2DH_HPCF_LOWEST        (0x03 << 4)  /* Lowest HP cutoff frequency */

/* CTRL_REG3 bits */
#define LIS2DH_I1_AOI1            BIT(6)       /* AOI1 interrupt on INT1 */

/* INT1_CFG bits - motion detection on any axis */
#define LIS2DH_INT1_XHIE          BIT(1)       /* X high event enable */
#define LIS2DH_INT1_YHIE          BIT(3)       /* Y high event enable */
#define LIS2DH_INT1_ZHIE          BIT(5)       /* Z high event enable */

/*
 * Device handles
 */

/* I2C device for direct register access */
static const struct device *i2c_dev;
#define LIS3DH_I2C_ADDR           0x19

/* GPIO for INT1 interrupt - P0.02 */
static const struct gpio_dt_spec int1_gpio = {
	.port = DEVICE_DT_GET(DT_NODELABEL(gpio0)),
	.pin = 2,
	.dt_flags = GPIO_ACTIVE_HIGH
};

/* Semaphore for interrupt signaling */
K_SEM_DEFINE(motion_sem, 0, 1);

/* GPIO callback data */
static struct gpio_callback int1_cb_data;

/*
 * Battery Monitoring
 */

/* ADC device */
static const struct device *adc_dev;
static bool adc_available = false;

/* Battery state */
static struct {
	uint16_t voltage_mv;
	uint8_t percentage;
	bool is_low;
	int64_t last_update_time;
} battery = {
	.voltage_mv = 3000,
	.percentage = 100,
	.is_low = false,
	.last_update_time = 0
};

/*
 * BLE Advertising Configuration
 */

/* Manufacturer data: [Company ID (2 bytes), Battery %, Low battery flag, Voltage (2 bytes LE)] */
static uint8_t mfg_data[] = {
	0xFF, 0xFF,  /* Company ID (0xFFFF = test/internal use) */
	100,         /* Battery percentage (0-100) */
	0x00,        /* Low battery flag (0x00 = OK, 0x01 = LOW) */
	0xB8, 0x0B   /* Voltage in mV, little-endian (0x0BB8 = 3000 mV) */
};

static const struct bt_data ad[] = {
	BT_DATA_BYTES(BT_DATA_FLAGS, (BT_LE_AD_GENERAL | BT_LE_AD_NO_BREDR)),
	BT_DATA_BYTES(BT_DATA_UUID16_ALL, 0xAA, 0xFE),
	BT_DATA(BT_DATA_MANUFACTURER_DATA, mfg_data, sizeof(mfg_data)),
};

static const struct bt_data sd[] = {
	BT_DATA(BT_DATA_NAME_COMPLETE, CONFIG_BT_DEVICE_NAME,
		sizeof(CONFIG_BT_DEVICE_NAME) - 1),
};

/* Connectable, scannable advertising for Android CDM compatibility */
static struct bt_le_adv_param adv_params = BT_LE_ADV_PARAM_INIT(
	BT_LE_ADV_OPT_CONN | BT_LE_ADV_OPT_SCANNABLE,
	0x0190,  /* 250ms min (400 * 0.625ms) */
	0x0280,  /* 400ms max (640 * 0.625ms) */
	NULL
);

/* Application state */
static struct {
	bool is_advertising;
	bool is_active;          /* true when in active mode (motion detected) */
	int64_t last_motion_time;
	int64_t duty_cycle_start; /* timestamp of current duty cycle phase start */
	bool duty_on;            /* true = advertising phase, false = pause phase */
} app_state;

/*
 * I2C Helper Functions
 */

static int lis3dh_read_reg(uint8_t reg, uint8_t *val)
{
	return i2c_write_read(i2c_dev, LIS3DH_I2C_ADDR, &reg, 1, val, 1);
}

static int lis3dh_write_reg(uint8_t reg, uint8_t val)
{
	uint8_t buf[2] = {reg, val};
	return i2c_write(i2c_dev, buf, 2, LIS3DH_I2C_ADDR);
}

/*
 * Battery Monitoring Functions
 */

/**
 * Initialize ADC for battery voltage measurement
 */
static int init_battery_adc(void)
{
	int err;

	adc_dev = DEVICE_DT_GET(ADC_NODE);
	if (!device_is_ready(adc_dev)) {
		LOG_ERR("ADC device not ready");
		return -ENODEV;
	}

	/* Configure ADC channel */
	struct adc_channel_cfg channel_cfg = {
		.gain = ADC_GAIN,
		.reference = ADC_REFERENCE,
		.acquisition_time = ADC_ACQ_TIME(ADC_ACQ_TIME_MICROSECONDS, 40),
		.channel_id = ADC_CHANNEL_ID,
		.input_positive = NRF_SAADC_INPUT_AIN1,  /* P0.03 */
		.input_negative = NRF_SAADC_INPUT_DISABLED,  /* Internal GND for single-ended */
	};

	err = adc_channel_setup(adc_dev, &channel_cfg);
	if (err) {
		LOG_ERR("ADC channel setup failed: %d", err);
		return err;
	}

	adc_available = true;
	LOG_INF("Battery ADC initialized (AIN1/P0.03, gain=1/6, ref=0.6V)");
	return 0;
}

/**
 * Read battery voltage using direct HAL access (bypasses Zephyr driver)
 * Returns voltage in millivolts (mV)
 */
static uint16_t read_battery_voltage_hal(void)
{
	static volatile int16_t hal_buffer;

	/* Disable SAADC while configuring */
	nrf_saadc_disable(NRF_SAADC);

	/* Configure channel 0: AIN1, gain 1/6, ref internal, single-ended */
	nrf_saadc_channel_config_t ch_cfg = {
		.resistor_p = NRF_SAADC_RESISTOR_DISABLED,
		.resistor_n = NRF_SAADC_RESISTOR_DISABLED,
		.gain       = NRF_SAADC_GAIN1_6,
		.reference  = NRF_SAADC_REFERENCE_INTERNAL,
		.acq_time   = NRF_SAADC_ACQTIME_40US,
		.mode       = NRF_SAADC_MODE_SINGLE_ENDED,
		.burst      = NRF_SAADC_BURST_DISABLED,
	};
	nrf_saadc_channel_init(NRF_SAADC, 0, &ch_cfg);
	nrf_saadc_channel_input_set(NRF_SAADC, 0, NRF_SAADC_INPUT_AIN1, NRF_SAADC_INPUT_DISABLED);

	/* Set resolution to 12-bit */
	nrf_saadc_resolution_set(NRF_SAADC, NRF_SAADC_RESOLUTION_12BIT);

	/* Configure result buffer */
	nrf_saadc_buffer_init(NRF_SAADC, (nrf_saadc_value_t *)&hal_buffer, 1);

	/* Enable and start */
	nrf_saadc_enable(NRF_SAADC);

	/* Clear events */
	nrf_saadc_event_clear(NRF_SAADC, NRF_SAADC_EVENT_STARTED);
	nrf_saadc_event_clear(NRF_SAADC, NRF_SAADC_EVENT_END);

	/* Start and wait */
	nrf_saadc_task_trigger(NRF_SAADC, NRF_SAADC_TASK_START);
	while (!nrf_saadc_event_check(NRF_SAADC, NRF_SAADC_EVENT_STARTED)) {}

	/* Trigger sample and wait for conversion */
	nrf_saadc_task_trigger(NRF_SAADC, NRF_SAADC_TASK_SAMPLE);
	while (!nrf_saadc_event_check(NRF_SAADC, NRF_SAADC_EVENT_END)) {}

	/* Stop SAADC */
	nrf_saadc_task_trigger(NRF_SAADC, NRF_SAADC_TASK_STOP);
	nrf_saadc_disable(NRF_SAADC);

	/* Convert to millivolts: (raw * 600mV * 6) / 4096 */
	int32_t voltage_mv = ((int32_t)hal_buffer * 600 * 6) / 4096;

	LOG_INF("[HAL] Raw ADC: %d, Voltage: %d mV", hal_buffer, voltage_mv);

	return (uint16_t)(voltage_mv > 0 ? voltage_mv : 0);
}

/**
 * Read battery voltage from ADC
 * Returns voltage in millivolts (mV)
 */
static uint16_t read_battery_voltage(void)
{
	/* Use direct HAL access for reliable single-ended measurement */
	return read_battery_voltage_hal();
}

/**
 * Convert battery voltage to percentage (0-100%)
 * Uses linear interpolation between LOW and FULL thresholds
 */
static uint8_t voltage_to_percentage(uint16_t voltage_mv)
{
	if (voltage_mv <= BATTERY_LOW_THRESHOLD_MV) {
		return 0;
	}
	if (voltage_mv >= BATTERY_FULL_MV) {
		return 100;
	}

	uint32_t range = BATTERY_FULL_MV - BATTERY_LOW_THRESHOLD_MV;
	uint32_t offset = voltage_mv - BATTERY_LOW_THRESHOLD_MV;
	return (uint8_t)((offset * 100) / range);
}

/**
 * Update battery status and BLE manufacturer data
 */
static void update_battery_status(void)
{
	battery.voltage_mv = read_battery_voltage();
	battery.percentage = voltage_to_percentage(battery.voltage_mv);
	battery.is_low = (battery.voltage_mv <= BATTERY_LOW_THRESHOLD_MV);
	battery.last_update_time = k_uptime_get();

	/* Update manufacturer data */
	mfg_data[2] = battery.percentage;
	mfg_data[3] = battery.is_low ? 0x01 : 0x00;
	/* Voltage in little-endian (low byte first) */
	mfg_data[4] = (uint8_t)(battery.voltage_mv & 0xFF);
	mfg_data[5] = (uint8_t)((battery.voltage_mv >> 8) & 0xFF);

	LOG_INF("[BATT] Voltage: %d mV, Percentage: %d%% %s",
		battery.voltage_mv, battery.percentage,
		battery.is_low ? "(LOW!)" : "(OK)");

	/* Update advertising data if currently advertising */
	if (app_state.is_advertising) {
		int err = bt_le_adv_update_data(ad, ARRAY_SIZE(ad), sd, ARRAY_SIZE(sd));
		if (err) {
			LOG_ERR("Failed to update advertising data: %d", err);
		}
	}
}

/*
 * GPIO Interrupt Callback
 *
 * Called when LIS3DH INT1 pin goes high (motion detected).
 * Wakes main thread from sleep via semaphore.
 */
static void int1_callback(const struct device *dev, struct gpio_callback *cb,
			  uint32_t pins)
{
	ARG_UNUSED(cb);
	ARG_UNUSED(pins);

	/* Disable interrupt to prevent re-triggering while pin is high */
	gpio_pin_interrupt_configure(dev, int1_gpio.pin, GPIO_INT_DISABLE);

	k_sem_give(&motion_sem);
}

/*
 * Configure LIS3DH for Hardware Motion Detection
 *
 * Sets up the accelerometer's internal motion detection engine:
 * - 1Hz ODR in low-power mode (~2µA)
 * - High-pass filter removes gravity, detects only acceleration changes
 * - Threshold interrupt on any axis exceeding configured mg value
 */
static int configure_hardware_motion(void)
{
	int err;
	uint8_t val;

	/* Verify WHO_AM_I */
	err = lis3dh_read_reg(LIS2DH_REG_WHO_AM_I, &val);
	if (err) {
		LOG_ERR("Failed to read WHO_AM_I: %d", err);
		return err;
	}
	if (val != LIS2DH_WHO_AM_I_VALUE) {
		LOG_ERR("Unexpected WHO_AM_I: 0x%02X (expected 0x%02X)",
			val, LIS2DH_WHO_AM_I_VALUE);
		return -ENODEV;
	}
	LOG_INF("LIS3DH detected (WHO_AM_I: 0x%02X)", val);

	/*
	 * CTRL_REG1: 1Hz ODR, low-power mode, all axes enabled
	 * - Lowest power consumption while still detecting motion
	 * - ~1 second wake latency (acceptable for presence detection)
	 */
	err = lis3dh_write_reg(LIS2DH_REG_CTRL_REG1,
			       LIS2DH_ODR_1HZ | LIS2DH_LPEN | LIS2DH_XYZ_EN);
	if (err) {
		LOG_ERR("Failed to configure CTRL_REG1: %d", err);
		return err;
	}

	/*
	 * CTRL_REG2: High-pass filter for interrupt 1
	 * - Removes DC gravity component
	 * - Only acceleration CHANGES trigger the interrupt
	 * - Lowest cutoff frequency for best motion detection
	 */
	err = lis3dh_write_reg(LIS2DH_REG_CTRL_REG2,
			       LIS2DH_HPCF_LOWEST | LIS2DH_HP_IA1);
	if (err) {
		LOG_ERR("Failed to configure CTRL_REG2: %d", err);
		return err;
	}

	/*
	 * CTRL_REG3: Route AOI1 (motion) interrupt to INT1 pin
	 */
	err = lis3dh_write_reg(LIS2DH_REG_CTRL_REG3, LIS2DH_I1_AOI1);
	if (err) {
		LOG_ERR("Failed to configure CTRL_REG3: %d", err);
		return err;
	}

	/*
	 * CTRL_REG4: Default (2g range, normal resolution)
	 * - 2g range provides 16mg/LSB for threshold calculation
	 */
	err = lis3dh_write_reg(LIS2DH_REG_CTRL_REG4, 0x00);
	if (err) {
		LOG_ERR("Failed to configure CTRL_REG4: %d", err);
		return err;
	}

	/*
	 * CTRL_REG5: Latch interrupt (INT1 stays high until INT1_SRC is read)
	 */
	err = lis3dh_write_reg(LIS2DH_REG_CTRL_REG5, BIT(3));  /* LIR_INT1 */
	if (err) {
		LOG_ERR("Failed to configure CTRL_REG5: %d", err);
		return err;
	}

	/*
	 * INT1_THS: Motion threshold
	 * - At 2g range: 1 LSB = 16mg
	 * - 32mg threshold = 2 LSBs
	 */
	uint8_t threshold_lsb = HW_MOTION_THRESHOLD_MG / 16;
	if (threshold_lsb < 1) {
		threshold_lsb = 1;
	}
	err = lis3dh_write_reg(LIS2DH_REG_INT1_THS, threshold_lsb);
	if (err) {
		LOG_ERR("Failed to configure INT1_THS: %d", err);
		return err;
	}

	/*
	 * INT1_DURATION: Samples above threshold before interrupt
	 * - 1 = immediate trigger (single sample above threshold)
	 */
	err = lis3dh_write_reg(LIS2DH_REG_INT1_DURATION, HW_MOTION_DURATION);
	if (err) {
		LOG_ERR("Failed to configure INT1_DURATION: %d", err);
		return err;
	}

	/*
	 * Read REFERENCE register to reset high-pass filter
	 * - Sets current position as "zero" reference
	 */
	err = lis3dh_read_reg(LIS2DH_REG_REFERENCE, &val);
	if (err) {
		LOG_ERR("Failed to read REFERENCE: %d", err);
		return err;
	}

	/*
	 * INT1_CFG: Enable high-event interrupt on all axes (OR combination)
	 * - Any axis exceeding threshold triggers interrupt
	 */
	err = lis3dh_write_reg(LIS2DH_REG_INT1_CFG,
			       LIS2DH_INT1_XHIE | LIS2DH_INT1_YHIE | LIS2DH_INT1_ZHIE);
	if (err) {
		LOG_ERR("Failed to configure INT1_CFG: %d", err);
		return err;
	}

	/*
	 * Clear any pending interrupts by reading INT1_SRC
	 */
	lis3dh_read_reg(LIS2DH_REG_INT1_SRC, &val);

	LOG_INF("HW motion OK: threshold=%dmg duration=%d ODR=1Hz",
		HW_MOTION_THRESHOLD_MG, HW_MOTION_DURATION);

	return 0;
}

/*
 * Clear Pending Motion Interrupt
 *
 * Reads INT1_SRC to clear the latched interrupt.
 */
static void clear_motion_interrupt(void)
{
	uint8_t val;
	lis3dh_read_reg(LIS2DH_REG_INT1_SRC, &val);
}

/*
 * Configure GPIO Interrupt for INT1 Pin
 */
static int configure_gpio_interrupt(void)
{
	int err;

	if (!gpio_is_ready_dt(&int1_gpio)) {
		LOG_ERR("INT1 GPIO not ready");
		return -ENODEV;
	}

	/* Configure as input */
	err = gpio_pin_configure_dt(&int1_gpio, GPIO_INPUT);
	if (err) {
		LOG_ERR("Failed to configure INT1 GPIO: %d", err);
		return err;
	}

	/* Setup callback */
	gpio_init_callback(&int1_cb_data, int1_callback, BIT(int1_gpio.pin));
	err = gpio_add_callback(int1_gpio.port, &int1_cb_data);
	if (err) {
		LOG_ERR("Failed to add INT1 callback: %d", err);
		return err;
	}

	/* Clear any pending LIS3DH interrupt before enabling GPIO interrupt */
	clear_motion_interrupt();
	k_msleep(10);
	clear_motion_interrupt();

	/* Enable rising edge interrupt (uses low-power SENSE via sense-edge-mask in DTS) */
	err = gpio_pin_interrupt_configure_dt(&int1_gpio, GPIO_INT_EDGE_TO_ACTIVE);
	if (err) {
		LOG_ERR("Failed to configure INT1 interrupt: %d", err);
		return err;
	}

	LOG_INF("GPIO interrupt configured on pin %d", int1_gpio.pin);
	return 0;
}

/*
 * BLE Advertising Control
 */

static int start_advertising(void)
{
	if (app_state.is_advertising) {
		return 0;
	}

	int err = bt_le_adv_start(&adv_params, ad, ARRAY_SIZE(ad), sd, ARRAY_SIZE(sd));
	if (err && err != -EALREADY) {
		LOG_ERR("Failed to start advertising: %d", err);
		return err;
	}

	app_state.is_advertising = true;
	LOG_INF(">>> BLE advertising STARTED (motion detected)");
	return 0;
}

static int stop_advertising(void)
{
	if (!app_state.is_advertising) {
		return 0;
	}

	int err = bt_le_adv_stop();
	if (err && err != -EALREADY) {
		LOG_ERR("Failed to stop advertising: %d", err);
		return err;
	}

	app_state.is_advertising = false;
	LOG_INF("<<< BLE advertising STOPPED (no motion timeout)");
	return 0;
}

/*
 * Enter active mode: start advertising and begin duty cycle
 */
static void enter_active_mode(void)
{
	app_state.is_active = true;
	app_state.duty_on = true;
	app_state.duty_cycle_start = k_uptime_get();
	start_advertising();
}

/*
 * Leave active mode: stop advertising and clear state
 */
static void leave_active_mode(void)
{
	stop_advertising();
	app_state.is_active = false;
	app_state.duty_on = false;
}

/*
 * Main Application Loop
 *
 * State machine:
 * - SLEEP: MCU sleeps indefinitely waiting for motion interrupt
 * - ACTIVE: BLE advertising with duty cycle (7s on / 14s off),
 *           check for no-motion timeout, process new motion events
 */
static void run_main_loop(void)
{
	while (1) {
		if (app_state.is_active) {
			/*
			 * ACTIVE MODE: Duty-cycled advertising
			 * Advertise for ADV_DUTY_ON_SEC, then pause for ADV_DUTY_OFF_SEC.
			 * Continue until NO_MOTION_TIMEOUT_SEC of inactivity.
			 */

			/* Wait for motion interrupt with 500ms timeout for periodic checks */
			int sem_ret = k_sem_take(&motion_sem, K_MSEC(500));
			int64_t now = k_uptime_get();

			if (sem_ret == 0) {
				/* Motion detected - reset no-motion timeout */
				app_state.last_motion_time = now;
				clear_motion_interrupt();
				LOG_DBG("Motion interrupt");
			}

			/* Re-enable GPIO interrupt */
			gpio_pin_interrupt_configure_dt(&int1_gpio, GPIO_INT_EDGE_TO_ACTIVE);

			/* Check for battery update interval (every 5 minutes) */
			int64_t battery_elapsed_sec = (now - battery.last_update_time) / 1000;
			if (battery_elapsed_sec >= BATTERY_UPDATE_INTERVAL_SEC) {
				update_battery_status();
			}

			/* Check for no-motion timeout */
			int64_t elapsed_sec = (now - app_state.last_motion_time) / 1000;
			if (elapsed_sec >= NO_MOTION_TIMEOUT_SEC) {
				leave_active_mode();
				continue;
			}

			/* Manage advertising duty cycle */
			int64_t duty_elapsed_sec = (now - app_state.duty_cycle_start) / 1000;

			if (app_state.duty_on && duty_elapsed_sec >= ADV_DUTY_ON_SEC) {
				/* ON phase expired -> switch to OFF */
				stop_advertising();
				app_state.duty_on = false;
				app_state.duty_cycle_start = now;
				LOG_INF("Duty cycle: advertising OFF for %ds", ADV_DUTY_OFF_SEC);
			} else if (!app_state.duty_on && duty_elapsed_sec >= ADV_DUTY_OFF_SEC) {
				/* OFF phase expired -> switch to ON */
				start_advertising();
				app_state.duty_on = true;
				app_state.duty_cycle_start = now;
				LOG_INF("Duty cycle: advertising ON for %ds", ADV_DUTY_ON_SEC);
			}
		} else {
			/*
			 * SLEEP MODE: Ultra-low power, waiting for motion
			 */
			LOG_INF("Entering sleep (waiting for motion)...");

			/* Clear semaphore and any pending interrupts */
			k_sem_reset(&motion_sem);
			clear_motion_interrupt();

			/* Re-enable GPIO interrupt */
			gpio_pin_interrupt_configure_dt(&int1_gpio, GPIO_INT_EDGE_TO_ACTIVE);

			/* Check if INT1 is already high (motion during setup) */
			if (gpio_pin_get_dt(&int1_gpio)) {
				LOG_INF("INT1 already high - motion pending");
				clear_motion_interrupt();
				app_state.last_motion_time = k_uptime_get();
				enter_active_mode();
				continue;
			}

			/* Wait indefinitely for motion interrupt */
			k_sem_take(&motion_sem, K_FOREVER);

			/* Motion detected - wake up and start advertising */
			LOG_INF("Motion detected - waking up!");
			app_state.last_motion_time = k_uptime_get();
			clear_motion_interrupt();
			enter_active_mode();
		}
	}
}

int main(void)
{
	int err;

	/* Brief delay for hardware stabilization */
	k_msleep(100);

	LOG_INF("BLE Beacon | %s | thresh=%dmg timeout=%ds duty=%ds/%ds",
		CONFIG_BT_DEVICE_NAME, HW_MOTION_THRESHOLD_MG, NO_MOTION_TIMEOUT_SEC,
		ADV_DUTY_ON_SEC, ADV_DUTY_OFF_SEC);

	/* Get I2C device */
	i2c_dev = DEVICE_DT_GET(DT_NODELABEL(i2c0));
	if (!device_is_ready(i2c_dev)) {
		LOG_ERR("I2C device not ready");
		return -ENODEV;
	}

	/* Configure LIS3DH for hardware motion detection */
	LOG_INF("Configuring LIS3DH...");
	err = configure_hardware_motion();
	if (err) {
		LOG_ERR("Failed to configure hardware motion detection: %d", err);
		return err;
	}

	/* Configure GPIO interrupt */
	err = configure_gpio_interrupt();
	if (err) {
		LOG_ERR("Failed to configure GPIO interrupt: %d", err);
		return err;
	}

	/* Initialize battery monitoring */
	LOG_INF("Initializing battery ADC...");
	err = init_battery_adc();
	if (err) {
		LOG_WRN("Battery ADC init failed: %d (continuing without battery monitoring)", err);
	} else {
		/* Perform initial battery reading */
		update_battery_status();
	}

	/* Initialize Bluetooth */
	LOG_INF("Initializing Bluetooth...");
	err = bt_enable(NULL);
	if (err) {
		LOG_ERR("Bluetooth init failed: %d", err);
		return err;
	}
	LOG_INF("Bluetooth ready");

	/* Initialize state */
	app_state.is_advertising = false;
	app_state.is_active = false;
	app_state.last_motion_time = 0;
	app_state.duty_cycle_start = 0;
	app_state.duty_on = false;

	LOG_INF("Ready - move device to start advertising");

	/* Run main state machine */
	run_main_loop();

	return 0;
}
